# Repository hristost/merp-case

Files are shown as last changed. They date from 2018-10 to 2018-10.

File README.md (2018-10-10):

This is the OpenSCAD source for the acrylic plate and 3D-printed case I used
for my _merp_ keyboard. This can be adapted to support a variety of ortholinear
keyboards with arbitrary layout sizes and PCB mounting holes -- just read
through the first lines of the file that define 

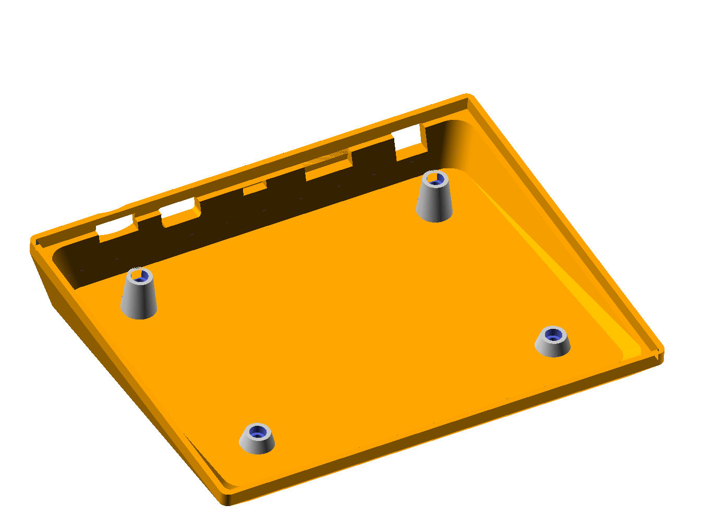
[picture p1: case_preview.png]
Model

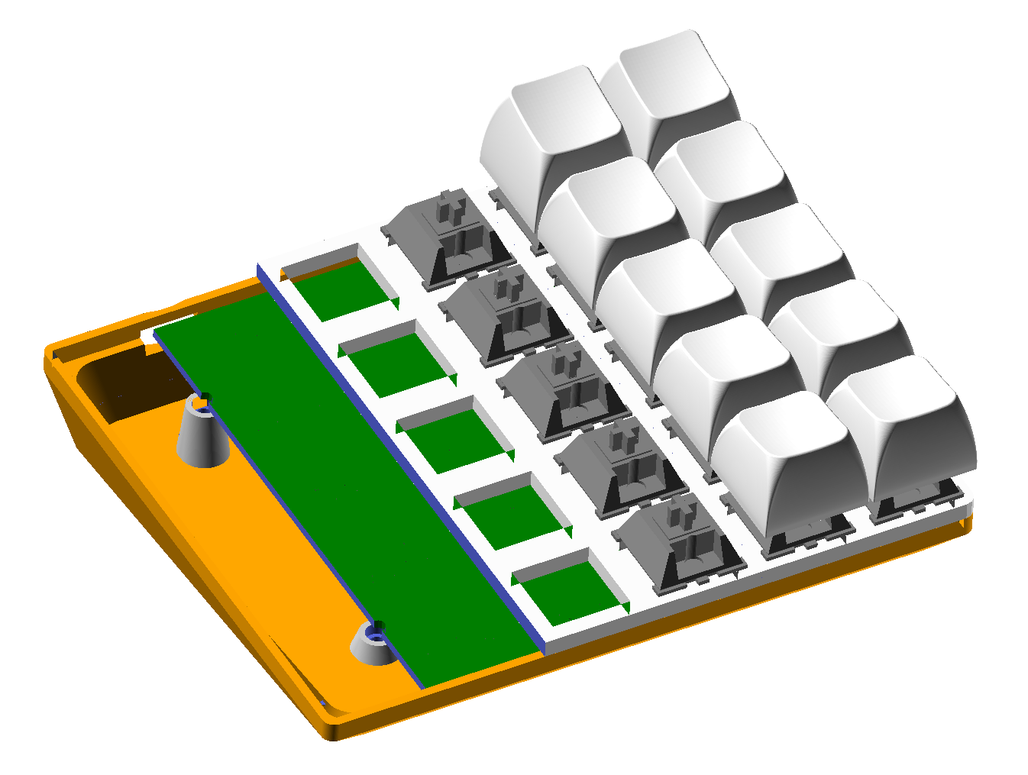
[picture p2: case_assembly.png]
Preview of the keyboard w/ keycaps on


Some notes:
 * This case is "borderless". This is mainly for aesthetic reasons in split 
 keyboards, where you'd probably want to be able to stick the two halves 
 together without creating an odd gap in the matrix
 * The case assumes standard Cherry MX switches on a 19mm gird
 * If you are using this for your own keyboard, make sure you have cut out 
 holes for USB, TRRS cables, etc at the correct locations. You can modify the
 `components()` module to import a 3D model of your PCB, so you can see if it
 fits without any issues

# Acknowledgements:
I use other people's models for creating the preview of the assembled keyboard:
* Cherry-MX switches from https://bitbucket.org/gcb/3dump
* Keycaps from https://www.thingiverse.com/thing:2178185

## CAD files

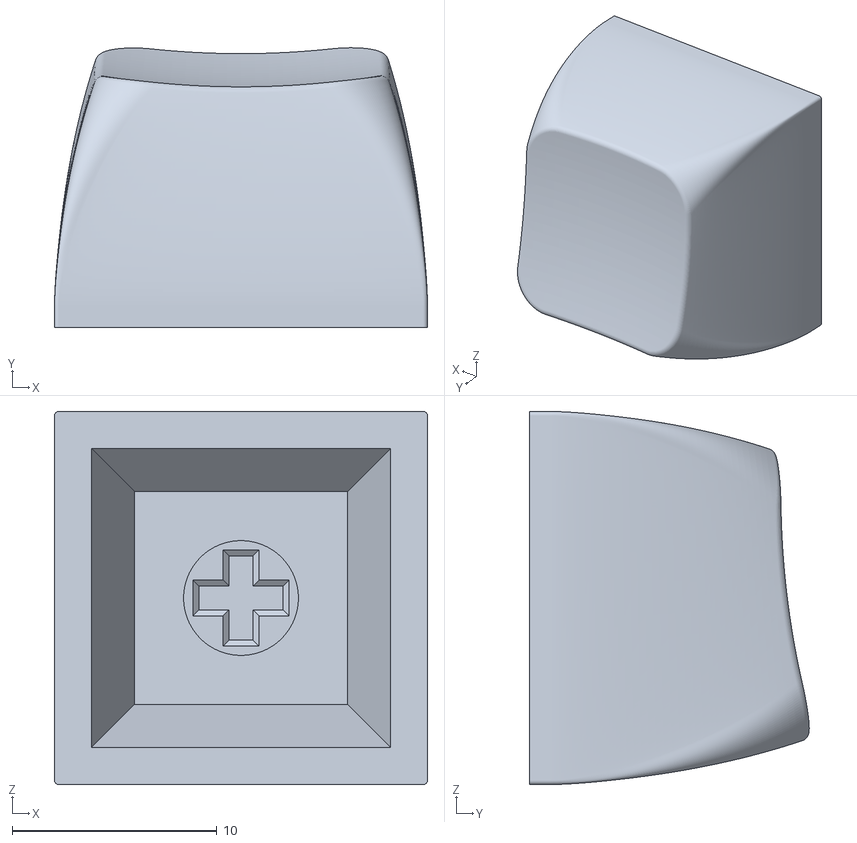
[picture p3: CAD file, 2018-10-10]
preview/SA_Row_4_1u.stl
18.2 x 13.6 x 18.2

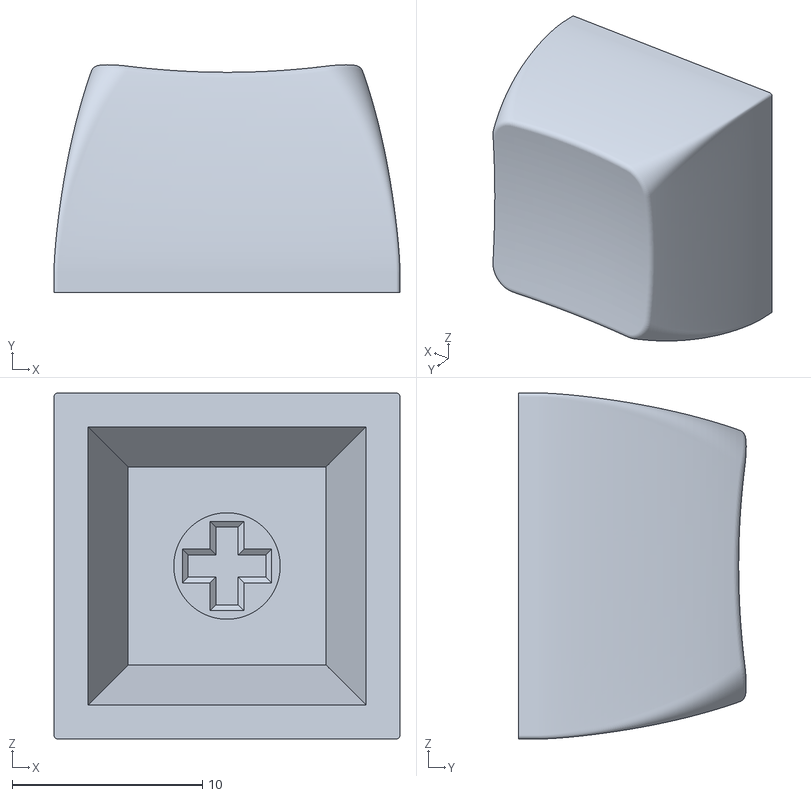
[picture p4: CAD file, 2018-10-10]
preview/SA_Row_3_1u.stl
18.2 x 12.0 x 18.2

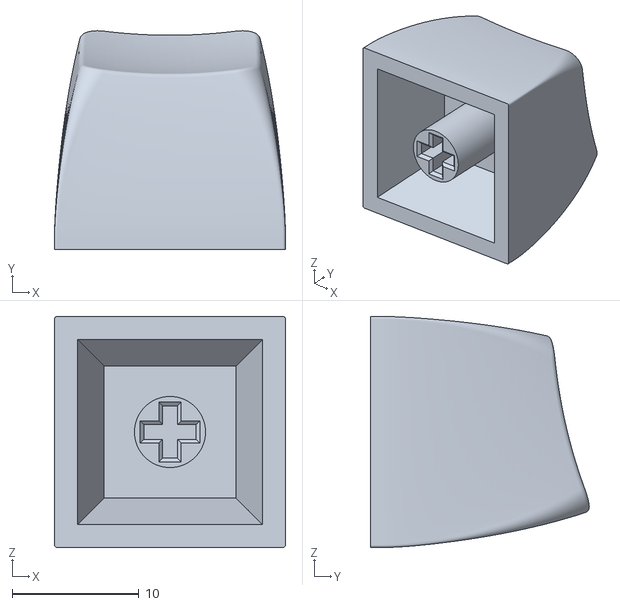
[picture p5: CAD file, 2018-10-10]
preview/SA_Row_1_1u.stl
18.2 x 17.2 x 18.2

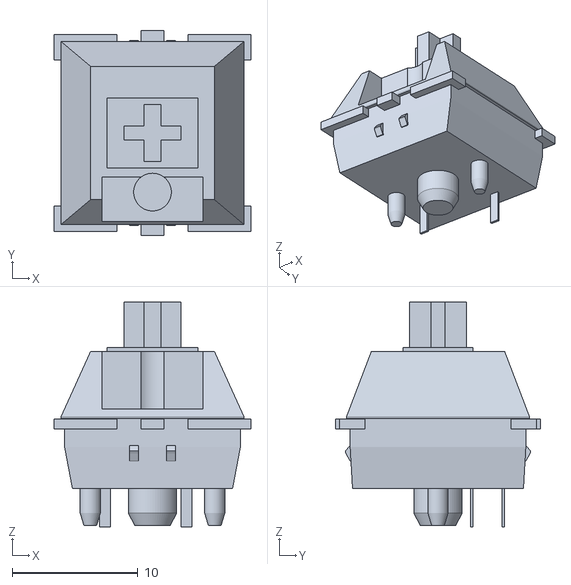
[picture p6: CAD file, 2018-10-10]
preview/switch_mx.stl
15.6 x 16.3 x 17.9

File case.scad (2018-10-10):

// vim: set foldmethod=marker:
use <rounded_rect.scad>;
$fn=12;
// How many rows of keys
rows=5;
// How many colums of keys
columns=6;
// Angle of the keyboard
angle = [6, 0, 0]; //º
// Thickness of case wall
wall=1.5;
// PCB thickness
pcb_h = 1.5;
// The gap between the pcb and the inner walls of the case
pcb_gap = 0.5;
// Acrylic plate thickness
acrylic_h = 3;
// What should be the smallest space between the PCB and the case bottom
case_h = 3;
// Radius of the 4 corners of the case and the mounting plate
case_r = 2;
// The size of the square holes made for switches. You want this to be slightly
// less than 14mm to compensate for the kerf of the laser cutter.
switch_hole_size = 13.6;
// Whether the plate should be surrounded by the case, or whether it should 
// completely cover it. Setting this to true makes the plate a bit more rigid,
// as there's space for more margin on the edges. Plus, it allows for light to 
// shine through
plate_over_case = true;
// Where to place mounting holes for screws that go through the plate and pcb
// Described in terms of rows/columns, [1, 1] means a hole between the 4 keys
// in the lower-left end of the keyboard
mounting_holes = [[1, 1], [columns-1, 1], [1, rows-1], [columns-1, rows-1]];
// The radius of the screws used.
mounting_screw_r = 2.4/2;
// The radius and height of the threaded insert embedded in the case
// 3dhubs.com/knowledge-base/how-assemble-3d-printed-parts-threaded-fasteners#inserts
mounting_nut_r = 2;
mounting_nut_h = 3;
// Bumpers: there are four inset circles on the bottom side used for glueing /
// silicone bumpers
// Radius of the bumper
bumper_leg_r = 4;
// How deep the inset should be -- 0.5 should be enough to be printable on most
// printers
bumper_leg_depth = 0.5;
// Distance between the center of the bumpers and the edge of the case
bumper_leg_inset = 13;

// For preview purposes only:
// The keycaps to use for each row (0 is bottom row)
// Link to stl file of keycap
profile = [ "preview/SA_Row_4_1u.stl", 
            "preview/SA_Row_4_1u.stl", 
            "preview/SA_Row_3_1u.stl", 
            "preview/SA_Row_2_1u.stl", 
            "preview/SA_Row_1_1u.stl"];
switch_model = "preview/switch_mx.stl";
// Rotation on Z to apply to the keycaps -- useful for flipping spacebars, etc
profile_rotation = [180, 180, 0, 0, 0];


// -------------------------- End of configuration -------------------------- 
//
/* Code for building case {{{*/
w = columns*19;
h = rows*19;



/// 2D image of the switch plate, with holes for switches and screws. OpenSCAD
/// can export this to SVG for use with laser cuttrs
module plate() {
    difference(){
        padding = plate_over_case ? [0, 0] : [1, 1]*(wall+pcb_gap);
        translate(padding)rounded_rect([w, h]-2*padding, case_r);

        for(x = [0 : columns-1]) {
            for(y = [0 : rows-1]) {
                translate([(19-switch_hole_size)/2, (19-switch_hole_size)/2])translate([x*19, y*19, 0]){
                    square([switch_hole_size, switch_hole_size]);
                }
            }    
        }
        for(hole = mounting_holes) {
            translate(hole*19)circle(r=mounting_screw_r);      
        }
    }
} 

/// Components not part of the case, used for generating a preview
/// Includes a PCB, switch plate, and if `switches` is true, MX switches and 
/// keycaps
module components(plate=true, switches=true, keycaps=true){
    rotate(angle){
        // PCB
        color("green")linear_extrude(height=pcb_h)difference(){
            padding = [1, 1]*(wall+pcb_gap);
            translate(padding)square([w, h]-2*padding);

            for(hole = mounting_holes) {
                translate(hole*19)circle(r=mounting_screw_r);      
            }
        }


        // Switches and keycaps    
        for(x = [0 : columns-1]) {
            for(y = [0 : rows-1]) {
                translate([19/2, 19/2, 0])translate([x*19, y*19, 0]){
                    if(switches || keycaps)
                        color("gray")translate([0, 0, 19.5])
                            import(switch_model);
                    if (keycaps)
                        color("white")translate([0, 0, 13])
                            rotate([0, 0, profile_rotation[y]])
                            rotate([90, 0, 0])import(profile[y]);
                }
            }    
        }

        // Acrylic plate
        if(plate)
            color("white")translate([0, 0, 5+pcb_h-acrylic_h])
            linear_extrude(height=acrylic_h)plate();
    }
}

/// The actual case of the keyboard. By default, it does not include any holes.
/// The first children gets subtracted from the walls of the case and is used
/// to make space for USB and other outlets. The second children gets 
/// subtracted from the mounting pegs in case they get in the way of components
/// on the PCB
module case() {
    color("orange"){

        difference(){
            union(){
                hull(){
                    // Top part
                    rotate(angle)scale([1, 1, -1])
                    linear_extrude(height=0.01)rounded_rect([w, h],case_r);
                    // Bottom -- lays flat on surface
                    translate([3, 3, -case_h])
                    linear_extrude(height=1)rounded_rect([w, h] - [6, 6], 5);
                }
                // If the plate is surrounded by the case, extrude additional 
                // 5mm (usual distance between PCB and top of switch plate)
                rotate(angle) 
                linear_extrude(height=5+pcb_h - (plate_over_case?acrylic_h:0))
                difference(){
                    translate([0, 0])rounded_rect([w, h], case_r);
                    translate([wall, wall])square([w, h]-[2, 2]*wall);
                }
            }
            // Make case hollow
            hull(){
                padding = [1, 1]*(wall+pcb_gap+1);
                rotate(angle)translate(padding)
                    linear_extrude(height=0.01)
                    rounded_rect([w, h] - padding*2,5);
                translate([3, 3, -case_h+wall]+[padding[0], padding[1], 0])
                    linear_extrude(height=0.01)
                    rounded_rect([w, h] - [6, 6] - 2*padding, 5);

            }
            // Cut out space for bumpers
            translate([bumper_leg_inset, bumper_leg_inset, -case_h - 0.1])
                cylinder(r=bumper_leg_r, height=0.1+bumper_leg_depth);
            translate([w-bumper_leg_inset, bumper_leg_inset, -case_h - 0.1])
                cylinder(r=bumper_leg_r, height=0.1+bumper_leg_depth);
            translate([bumper_leg_inset, h-bumper_leg_inset, -case_h - 0.1])
                cylinder(r=bumper_leg_r, height=0.1+bumper_leg_depth);
            translate([w-bumper_leg_inset, h-bumper_leg_inset, -case_h - 0.1])
                cylinder(r=bumper_leg_r, height=0.1+bumper_leg_depth);

            // Cut out space for sticker on bottom of the case
            translate([w/2-25, h/2-25, -case_h - 0.1])
            linear_extrude(height=0.35)rounded_rect([50,50], 5);

            // Holes for USB and others
            children(0);
        }
    }
    // Mounting holes
    difference() {
        // Stems
        union() for(hole = mounting_holes) hull(){
            rotate(angle)scale([1, 1, -1])linear_extrude(height=0.1){
                translate(hole*19)circle(r=mounting_nut_r+1);      
            }
            // Bottom face: Extrude the projection of the top face
            translate([0, 0, -case_h])
            linear_extrude(height=1) projection(cut = false)
            rotate(angle)scale([1, 1, -1])linear_extrude(height=10)
            translate(hole*19)circle(r=mounting_nut_r+2);      
        } 

        // Nuts
        rotate(angle)translate([0, 0, 1])scale([1, 1, -1]) {
            linear_extrude(height=mounting_nut_h+0.1) for(hole=mounting_holes) 
                translate(hole*19) circle(r=mounting_nut_r);      
        }
        // Screws
        rotate(angle)translate([0, 0, 1])scale([1, 1, -1]) {
            linear_extrude(height=mounting_nut_h+50) for(hole = mounting_holes)
                translate(hole*19)circle(r=mounting_screw_r+0.1);
        }
        // Other
        children(1);
    }
}
/*}}}*/

// By default, the case does not include any holes.
// The first children gets subtracted from the walls of the case and is used to
// make space for USB and other outlets. The second children gets subtracted
// from the mounting pegs in case they get in the way of components on the PCB
//
/// MERP: Left half
components();
case($fn=180){
toggle_position = 22;
    union(){
        // Right jack
        rotate(angle)translate([w-17-3.3-0.8, h-10, 0.3])scale([1, 1, -1])
            cube([6.4+1.6, 20, 6]);
        // Bluetooth module
        rotate(angle)translate([w-38.1-6, h-10, 0])scale([1, 1, -1])
            cube([12, 10-wall, 3.4]);
        // Misc SMDs
        rotate(angle)translate([w/2-3, h-10, 0])scale([1, 1, -1]
            )cube([6, 10-wall, 2]);
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

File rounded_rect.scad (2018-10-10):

module rounded_rect(size, radius, $fn=$fn) {
    hull(){
        translate([ 1,  1]*radius)circle(r=radius);
        translate([ 1, -1]*radius + [0, size[1]])circle(r=radius);
        translate([-1,  1]*radius + [size[0], 0])circle(r=radius);
        translate([-1, -1]*radius + size)circle(r=radius);
    }
}

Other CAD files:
preview/cherry_mx.scad
